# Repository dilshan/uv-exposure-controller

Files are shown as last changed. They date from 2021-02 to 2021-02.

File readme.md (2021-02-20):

## ATTiny2313 base electronic controller for UV exposure units.

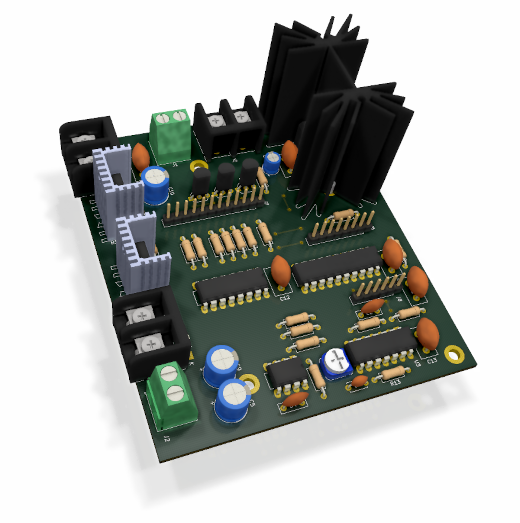
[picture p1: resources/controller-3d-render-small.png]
3D view of the controller PCB


*ATtiny2313A* MCU base exposure controller unit with two high-power relay driver stages, an audible notification unit, a safety lock, and a programmable timer. The programmable timer unit supports up to 999 seconds (approximately 16 minutes) of exposure.

This unit tests with four *NEC* 20W - 60cm (T8) black fluorescent tubes with four separate chokes and starter units.

The unit is specifically designed for developing screens (for screen-printing) and for paint curing.

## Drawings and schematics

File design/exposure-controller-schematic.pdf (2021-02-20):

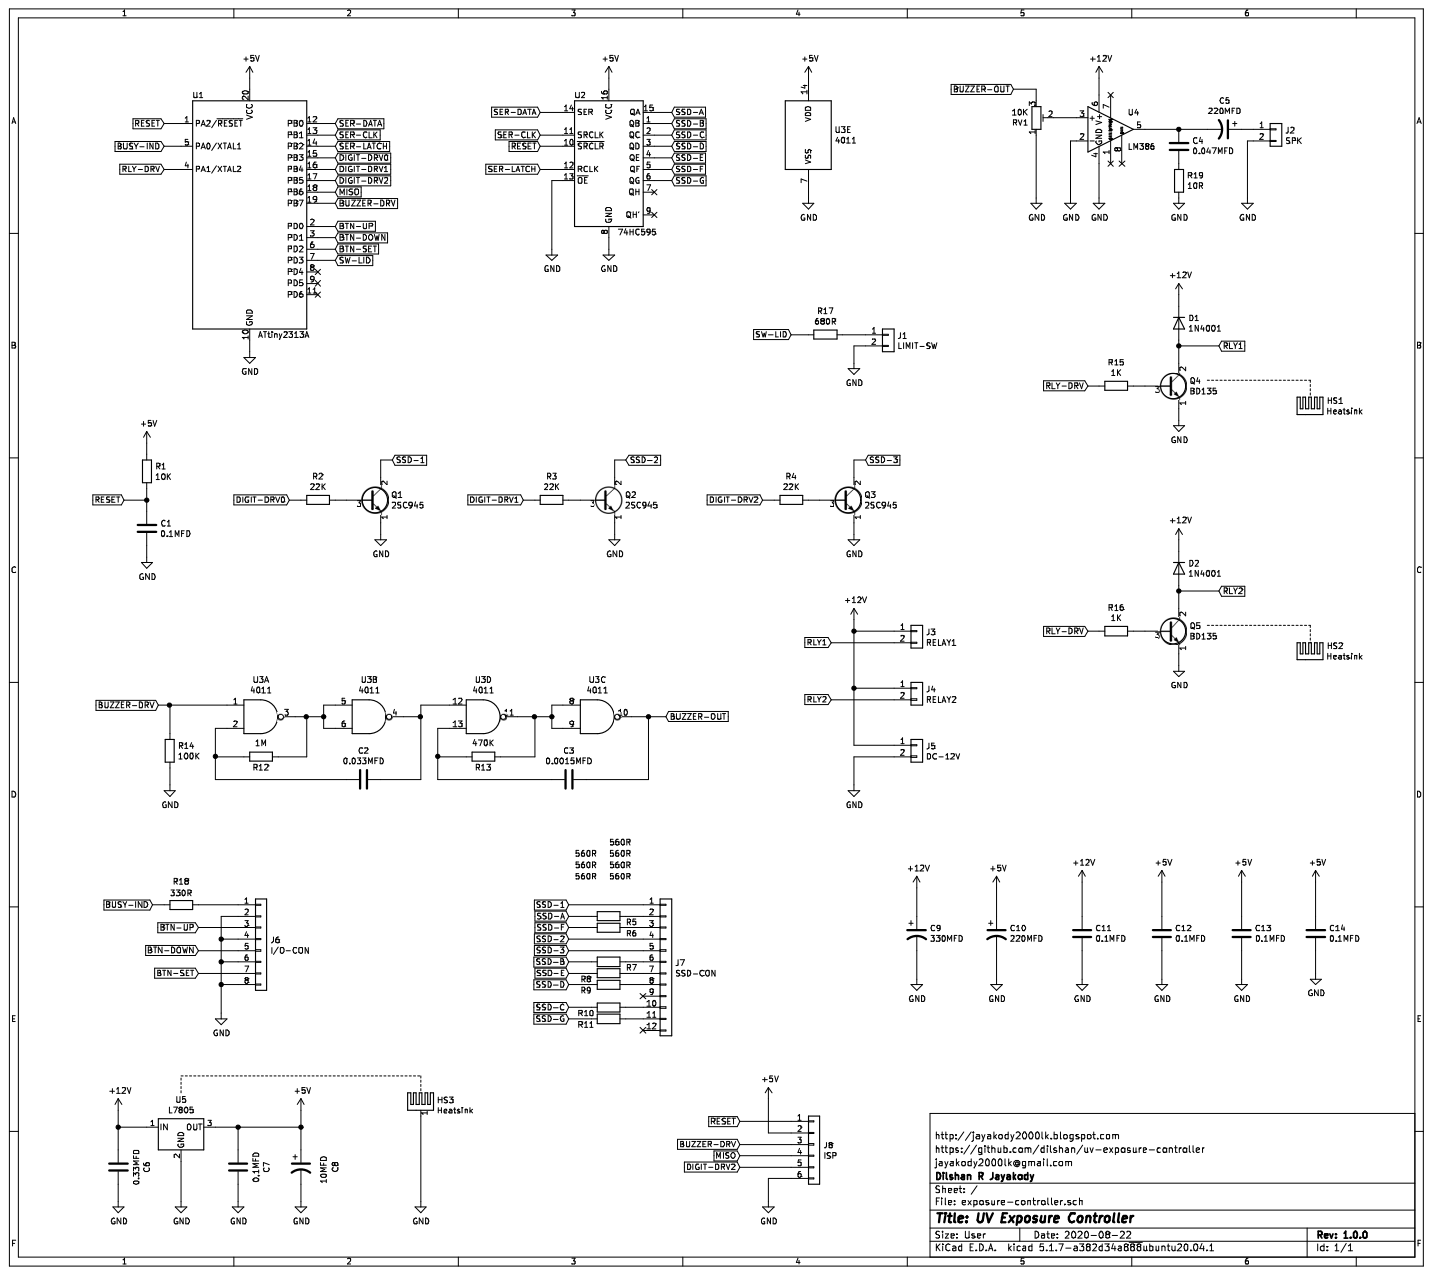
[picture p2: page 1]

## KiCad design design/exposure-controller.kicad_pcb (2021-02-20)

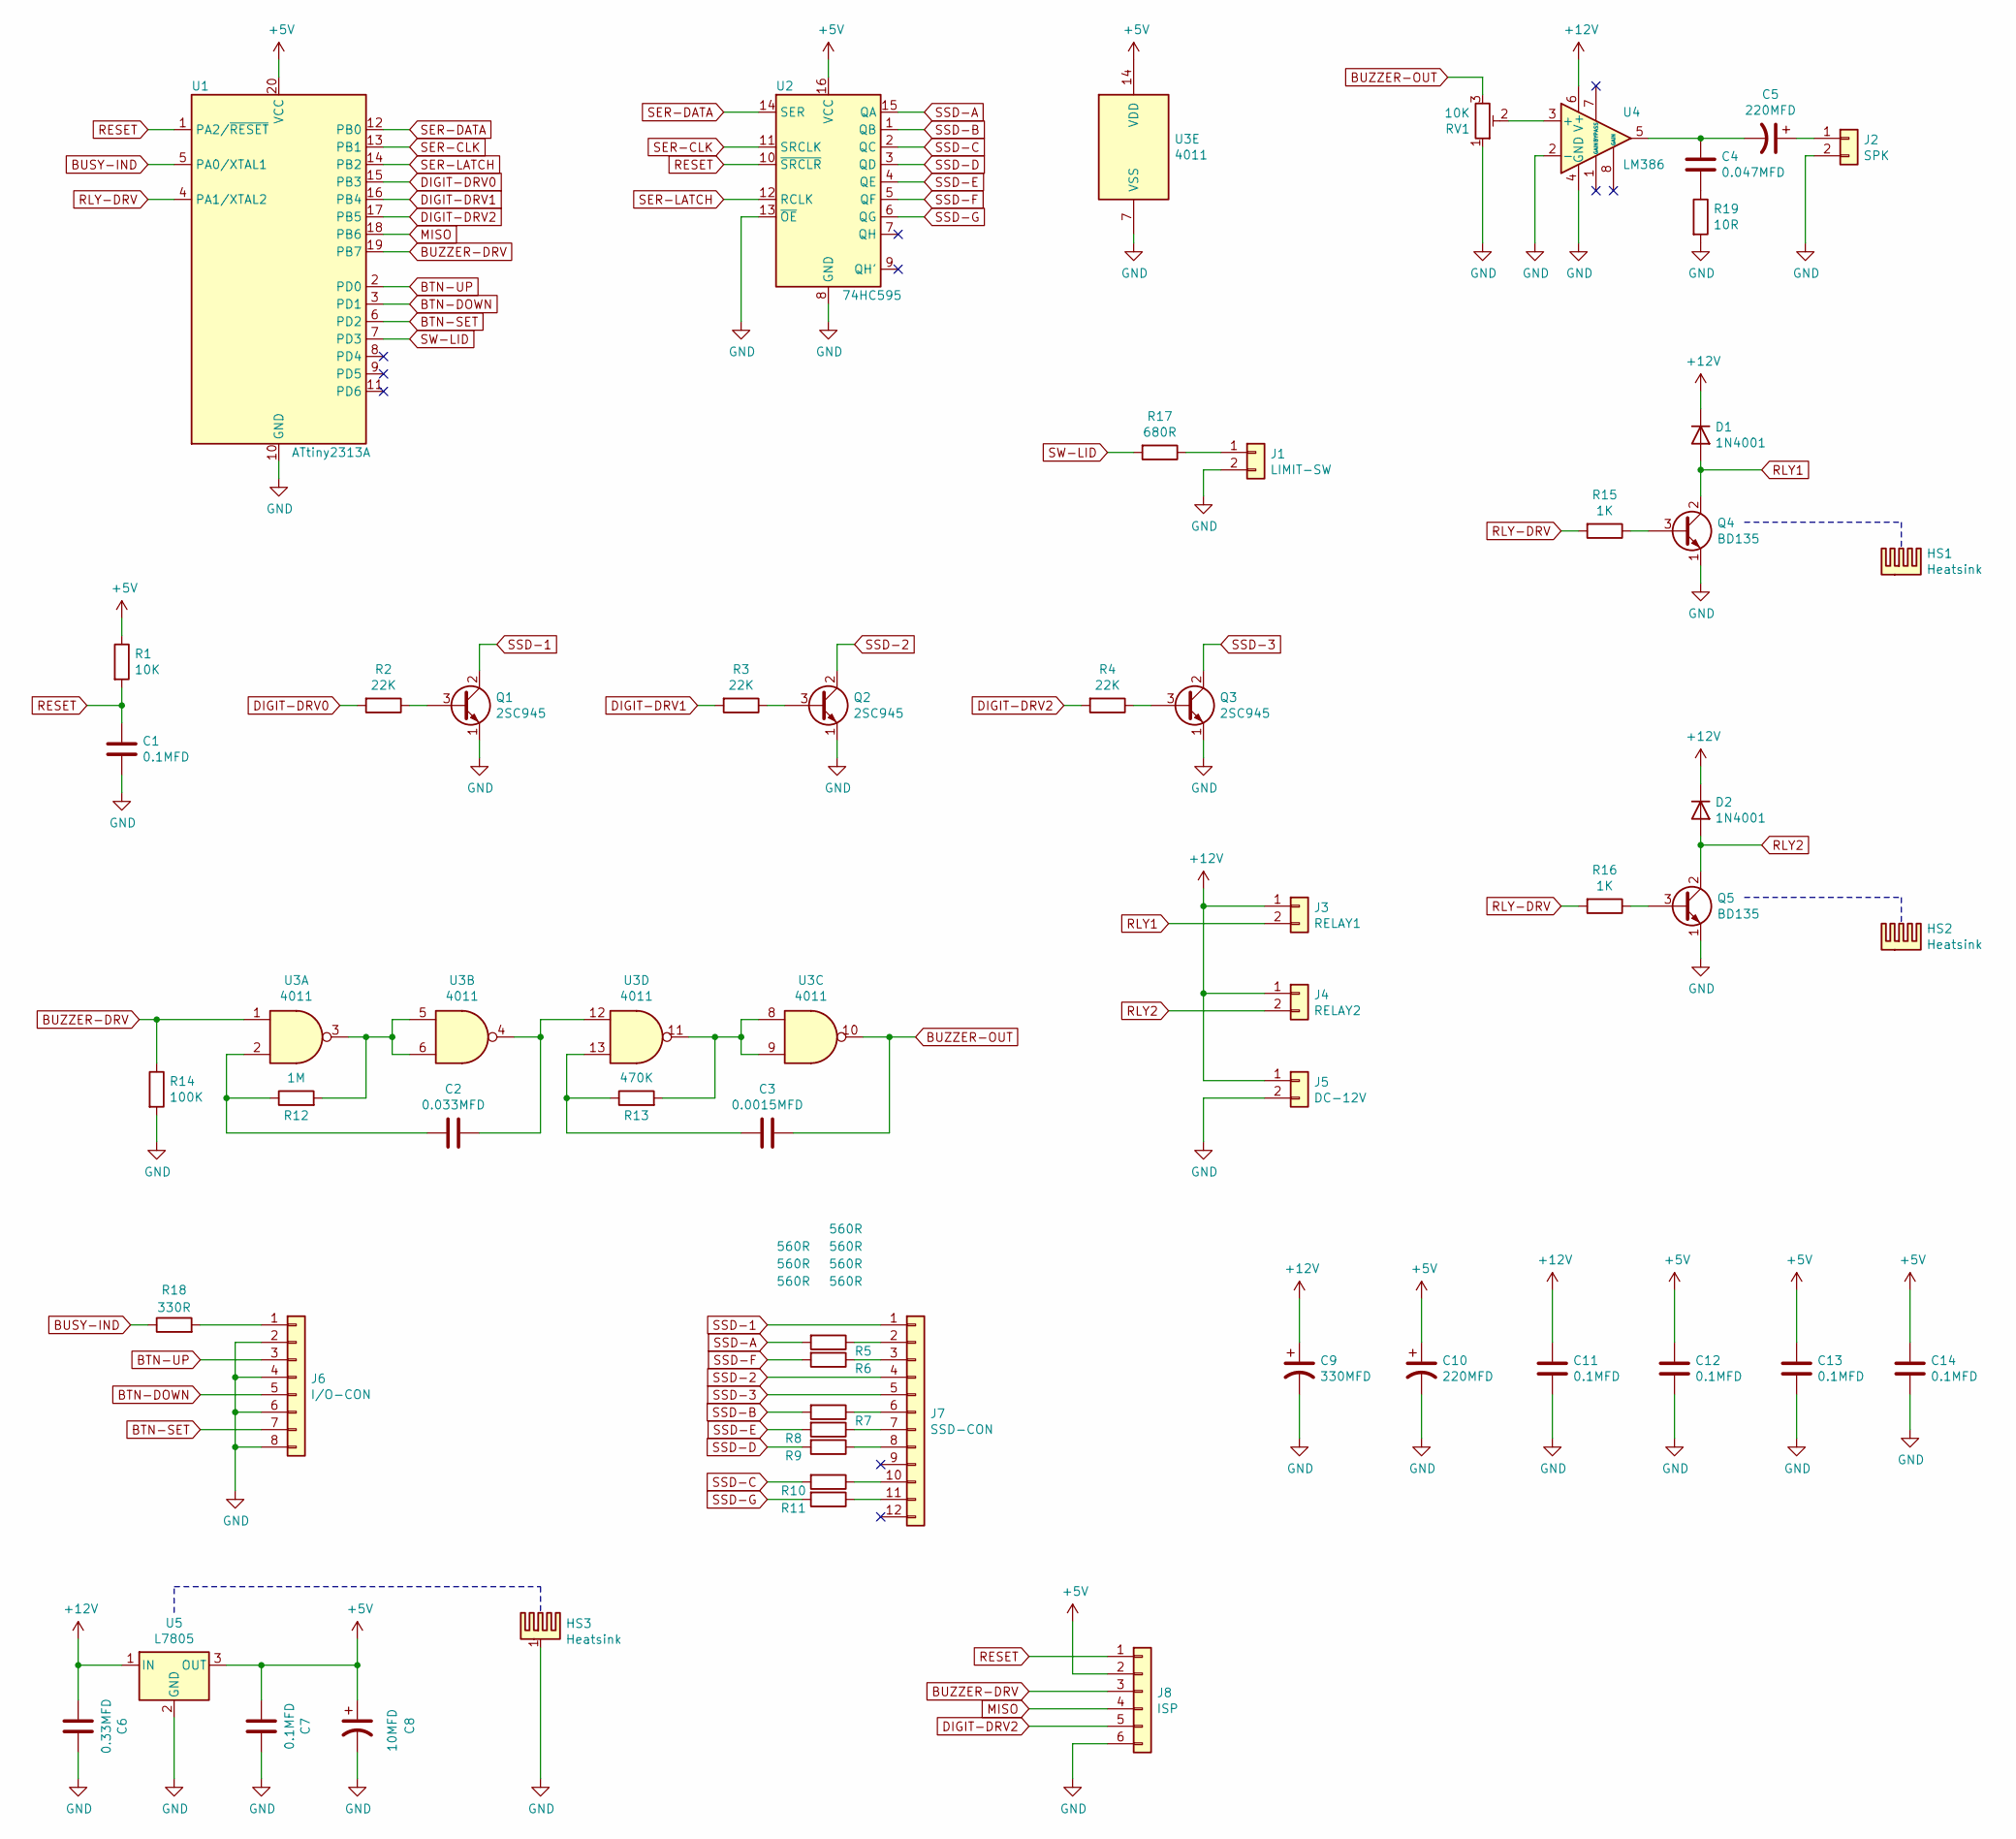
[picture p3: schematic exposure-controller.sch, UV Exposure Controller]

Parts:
C1, C7, C11, C12, C13, C14: 0.1MFD; C_Disc_D9.0mm_W5.0mm_P5.00mm
C2: 0.033MFD; C_Disc_D7.0mm_W2.5mm_P5.00mm
C3: 0.0015MFD; C_Disc_D4.7mm_W2.5mm_P5.00mm
C4: 0.047MFD; C_Disc_D7.0mm_W2.5mm_P5.00mm
C5, C10: 220MFD; CP_Radial_D8.0mm_P3.50mm
C6: 0.33MFD; C_Disc_D11.0mm_W5.0mm_P5.00mm
C8: 10MFD; CP_Radial_D5.0mm_P2.50mm
C9: 330MFD; CP_Radial_D8.0mm_P3.80mm
D1, D2: 1N4001; D_DO-41_SOD81_P10.16mm_Horizontal
HS1, HS2: Heatsink; Hetsink-21mm
HS3: Heatsink; Heatsink_Fischer_SK129-STS_42x25mm_2xDrill2.5mm
J1: LIMIT-SW; TerminalBlock_Phoenix_MKDS-1,5-2-5.08_1x02_P5.08mm_Horizont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
J2: SPK; TerminalBlock_Phoenix_MKDS-1,5-2-5.08_1x02_P5.08mm_Horizont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
J3: RELAY1; MENGFEI 8.5mm screw terminal - 2way
J4: RELAY2; MENGFEI 8.5mm screw terminal - 2way
J5: DC-12V; MENGFEI 8.5mm screw terminal - 2way
J6: I/O-CON; PinHeader_1x08_P2.54mm_Vertical
J7: SSD-CON; PinHeader_1x12_P2.54mm_Vertical
J8: ISP; PinHeader_1x06_P2.54mm_Vertical
Q1, Q2, Q3: 2SC945; TO-92L_Inline_Wide
Q4, Q5: BD135; TO-126-3_Vertical
R1: 10K; R_Axial_DIN0207_L6.3mm_D2.5mm_P10.16mm_Horizontal
R2, R3, R4: 22K; R_Axial_DIN0207_L6.3mm_D2.5mm_P10.16mm_Horizontal
R5, R6, R7, R8, R9, R10, R11: 560R; R_Axial_DIN0207_L6.3mm_D2.5mm_P10.16mm_Horizontal
R12: 1M; R_Axial_DIN0207_L6.3mm_D2.5mm_P10.16mm_Horizontal
R13: 470K; R_Axial_DIN0207_L6.3mm_D2.5mm_P10.16mm_Horizontal
R14: 100K; R_Axial_DIN0207_L6.3mm_D2.5mm_P10.16mm_Horizontal
R15, R16: 1K; R_Axial_DIN0207_L6.3mm_D2.5mm_P10.16mm_Horizontal
R17: 680R; R_Axial_DIN0207_L6.3mm_D2.5mm_P10.16mm_Horizontal
R18: 330R; R_Axial_DIN0207_L6.3mm_D2.5mm_P10.16mm_Horizontal
R19: 10R; R_Axial_DIN0207_L6.3mm_D2.5mm_P10.16mm_Horizontal
RV1: 10K; Potentiometer_Runtron_RM-065_Vertical
U1: ATtiny2313A; DIP-20_W7.62mm_LongPads
U2: 74HC595; DIP-16_W7.62mm_LongPads
U3: 4011; DIP-14_W7.62mm_LongPads
U4: LM386; DIP-8_W7.62mm_LongPads
U5: L7805; TO-220-3_Vertical

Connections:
+5V: C7.2, C8.1, C10.1, C12.1, C13.1, C14.1, J8.2, R1.1, U1.20 (VCC), U2.16 (VCC), U3.14 (VDD), U5.3 (OUT)
+12V: C6.2, C9.1, C11.1, D1.1 (K), D2.1 (K), J3.1, J4.1, J5.1, U4.6 (V+), U5.1 (IN)
BTN-DOWN: J6.5, U1.3 (PD1)
BTN-SET: J6.7, U1.6 (PD2)
BTN-UP: J6.3, U1.2 (PD0)
BUSY-IND: R18.1, U1.5 (PA0/XTAL1)
BUZZER-DRV: J8.3, R14.1, U1.19 (PB7), U3.1
BUZZER-OUT: C3.1, RV1.3, U3.10
DIGIT-DRV0: R2.2, U1.15 (PB3)
DIGIT-DRV1: R3.2, U1.16 (PB4)
DIGIT-DRV2: J8.5, R4.2, U1.17 (PB5)
GND: C1.2, C6.1, C7.1, C8.2, C9.2, C10.2, C11.2, C12.2, C13.2, C14.2, HS3.1, J1.2, J2.2, J5.2, J6.2, J6.4, J6.6, J6.8, J8.6, Q1.1 (E), Q2.1 (E), Q3.1 (E), Q4.1 (E), Q5.1 (E), R14.2, R19.2, RV1.1, U1.10 (GND), U2.8 (GND), U2.13 (~OE), U3.7 (VSS), U4.2 (-), U4.4 (GND), U5.2 (GND)
MISO: J8.4, U1.18 (PB6)
unnamed: C2.1, U3.4, U3.12
unnamed: C2.2, R12.1, U3.2
unnamed: C3.2, R13.1, U3.13
unnamed: C4.1, R19.1
unnamed: C4.2, C5.2, U4.5
unnamed: C5.1, J2.1
unnamed: J1.1, R17.1
unnamed: J6.1, R18.2
unnamed: J7.2, R5.1
unnamed: J7.3, R6.1
unnamed: J7.6, R7.1
unnamed: J7.7, R8.1
unnamed: J7.8, R9.1
unnamed: J7.10, R10.1
unnamed: J7.11, R11.1
unnamed: Q1.3 (B), R2.1
unnamed: Q2.3 (B), R3.1
unnamed: Q3.3 (B), R4.1
unnamed: Q4.3 (B), R15.1
unnamed: Q5.3 (B), R16.1
unnamed: R12.2, U3.3, U3.5, U3.6
unnamed: R13.2, U3.8, U3.9, U3.11
unnamed: RV1.2, U4.3 (+)
RESET: C1.1, J8.1, R1.2, U1.1 (PA2/~RESET), U2.10 (~SRCLR)
RLY1: D1.2 (A), J3.2, Q4.2 (C)
RLY2: D2.2 (A), J4.2, Q5.2 (C)
RLY-DRV: R15.2, R16.2, U1.4 (PA1/XTAL2)
SER-CLK: U1.13 (PB1), U2.11 (SRCLK)
SER-DATA: U1.12 (PB0), U2.14 (SER)
SER-LATCH: U1.14 (PB2), U2.12 (RCLK)
SSD-1: J7.1, Q1.2 (C)
SSD-2: J7.4, Q2.2 (C)
SSD-3: J7.5, Q3.2 (C)
SSD-A: R5.2, U2.15 (QA)
SSD-B: R7.2, U2.1 (QB)
SSD-C: R10.2, U2.2 (QC)
SSD-D: R9.2, U2.3 (QD)
SSD-E: R8.2, U2.4 (QE)
SSD-F: R6.2, U2.5 (QF)
SSD-G: R11.2, U2.6 (QG)
SW-LID: R17.2, U1.7 (PD3)

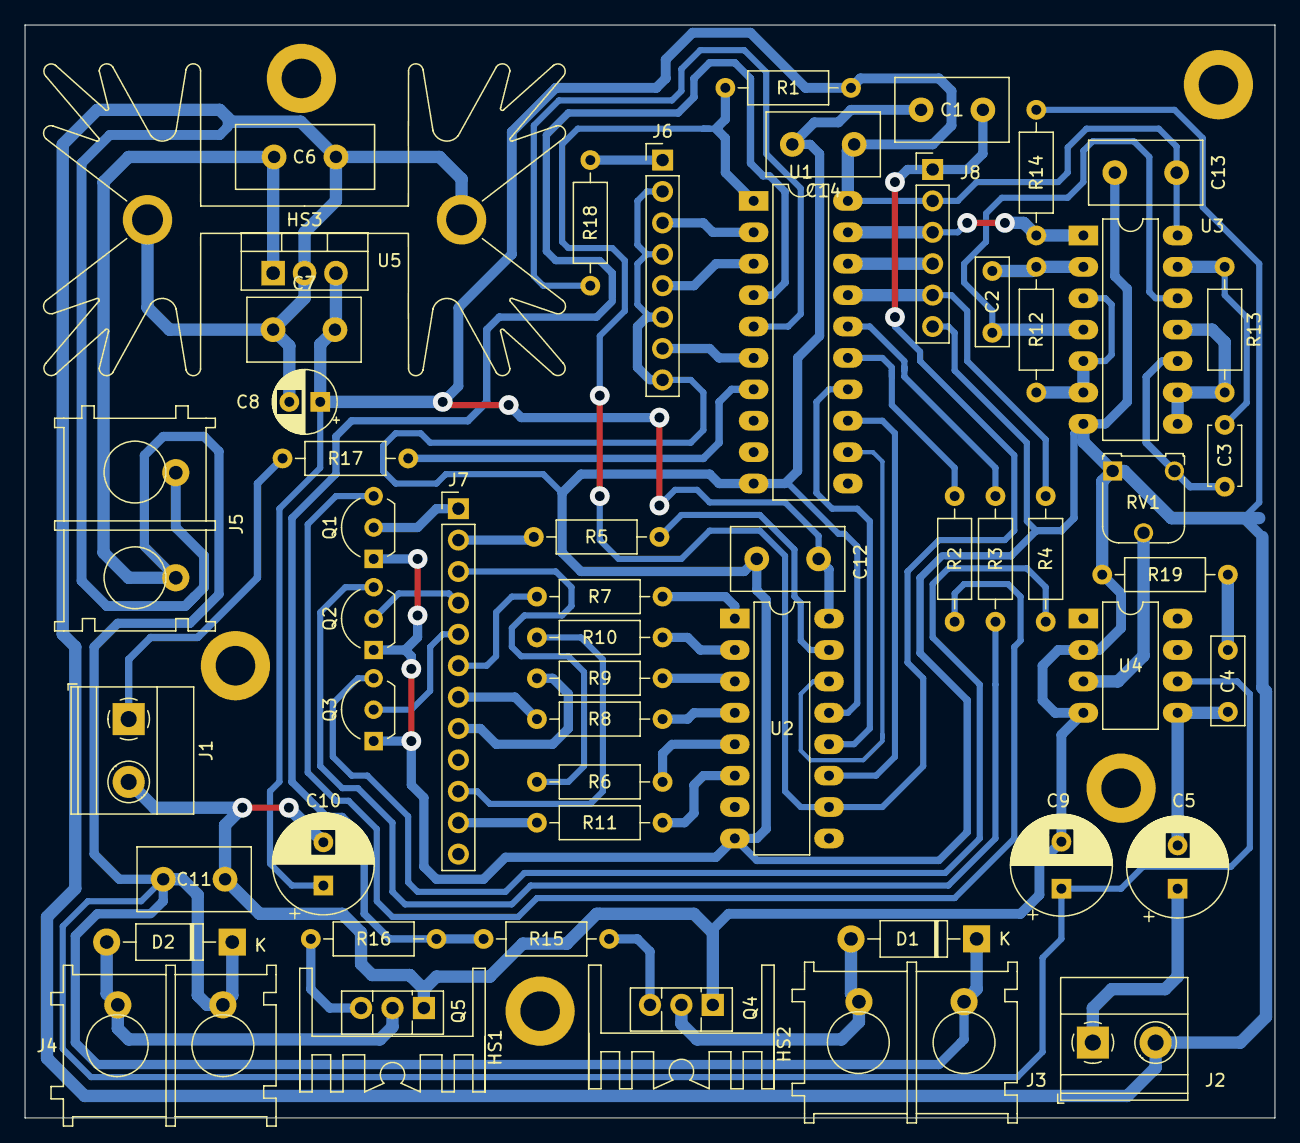
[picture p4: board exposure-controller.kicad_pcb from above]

Board: 2 copper layers, 101.1 x 88.4 mm, 62 parts (0 on the bottom side), 54 nets.

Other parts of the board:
 : MountingHole_3.2mm_M3_DIN965_Pad
 #2,  #3,  #4,  #5: MountingHole_3.2mm_M3_DIN965_Pad

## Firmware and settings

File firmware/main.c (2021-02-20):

//-----------------------------------------------------------------------
// Copyright 2020 Dilshan R Jayakody [jayakody2000lk@gmail.com]
//
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
#include <avr/io.h>

#include "main.h"

#include <util/delay.h>
#include <avr/interrupt.h>
#include <avr/eeprom.h>
#include <avr/wdt.h>

typedef enum SytemState 
{
    IdleState,  // System is in idle state (waiting for action).
    EditState,  // Digit edit state.
    RunState,   // UV timer execute state.
    PauseState  // Timer pause state due to external interrupt.
} SytemState;

SytemState currentState;

uint8_t timerCounter, editDigit;
uint8_t buzzerCounter;
int16_t time, targetTime;

int main()
{
    // Stop Timer 1 and WDT.
    cli();
    wdt_disable();

    TCCR1B = 0x00;
    
    uint8_t lastSwitchState, tempDigit;
    currentState = IdleState;

    // Setup I/O ports.

    // A0 -> Run indicator.
    // A1 -> Relay driver.
    DDRA = 0x03;
    PORTA = 0x00;

    // B0 -> 74HC595 : SER (Serial Input).
    // B1 -> 74HC595 : SRCLK (Shift Register Clock).
    // B2 -> 74HC595 : RCLK (Register Clock).
    // B3 -> Digit 1 driver.
    // B4 -> Digit 2 driver.
    // B5 -> Digit 3 driver.
    // B7 -> 4011 : Buzzer.
    DDRB = 0xFF;
    PORTB = 0x00;

    // D0 -> UP / START button input.
    // D1 -> DOWN / STOP button input.
    // D2 -> SET button input.
    // D3 -> Lid open limit switch.
    DDRD = 0x00;
    PORTD = 0xFF;  

    // Wait to avoid startup spikes.
    _delay_ms(1000);
     
    editDigit = 0;
    timerCounter = 0;
    targetTime = time = MINIMUM_TIME;
    buzzerCounter = 0;

    // Start Timer 1 with 2Hz output.
    TCNT1 = 0;
    OCR1A = 15624;
    
    TCCR1A = 0x00;
    TCCR1B = 0x0C;
    TIMSK = TIMSK | 0x40;

    sei();

    lastSwitchState = PIND; 
    wdt_enable(WDTO_4S);

    // Read time setting from EEPROM and validate the limits.
    time = eeprom_read_word((uint16_t * )0);
    if((time < MINIMUM_TIME) || (time > MAXIMUM_TIME))
    {
        // Current time is out of bounds.
        time = MINIMUM_TIME;
    }

    wdt_reset();
    targetTime = time;

    // Main service loop.
    while (1)
    {
        if(((PIND & 0x01) == 0x01) && ((lastSwitchState & 0x01) == 0x00))
        {
            // Start / Increment button pressed.
            if(currentState == EditState)
            {
                // Increase the value of the current digit.
                tempDigit = extractDigit();
                tempDigit = ((tempDigit == 9) ? 0 : (tempDigit + 1));
                updateDigit(tempDigit);

                timerCounter = 0;                
            }
            else if(currentState == IdleState)
            {                
                // Start UV timer.
                time = targetTime;
                timerCounter = 0;
                PORTA = 0x03;
                currentState = RunState;
            }
        }

        if(((PIND & 0x02) == 0x02) && ((lastSwitchState & 0x02) == 0x00))
        {
            // Stop / Decrement button pressed.
            if(currentState == EditState)
            {
                // Decrease the value of the current digit.
                tempDigit = extractDigit();
                tempDigit = ((tempDigit == 0) ? 9 : (tempDigit - 1));
                updateDigit(tempDigit);

                timerCounter = 0;
            }
            else if(currentState == RunState)
            {
                // Stop UV timer.
                currentState = IdleState;
                time = targetTime;                
                PORTA = 0x00;

                // Trigger buzzer with short beep.
                timerCounter = 1;
                buzzerCounter = 2;
                PORTB = PORTB | 0x80;
            }
        }

        if(((PIND & 0x04) == 0x04) && ((lastSwitchState & 0x04) == 0x00))
        {
            // Set button pressed.
            if(currentState == IdleState)
            {
                // Enter into time edit mode.
                currentState = EditState;
                editDigit = 0;
            }
            else if(currentState == EditState)
            {
                // Move editor into next digit.
                editDigit++;

                if(editDigit > 2)
                {
                    // All digits are updated and leave the edit mode.
                    if(time < MINIMUM_TIME)
                    {
                        // Specified time is less than minimum time interval. Reset time to minimum.
                        time = MINIMUM_TIME;
                    }

                    editDigit = 0;
                    targetTime = time;

                    // Load new time value into EEPROM.
                    wdt_reset();
                    if(targetTime != eeprom_read_word((uint16_t * )0))
                    {
                        eeprom_write_word((uint16_t*)0, targetTime);
                    }

                    wdt_reset();
                    currentState = IdleState;
                }
            }
        }

        if(currentState == RunState)
        {            
            if(time <= 0)
            {            
                // UV exposure countdown completed.
                currentState = IdleState;
                time = targetTime;
                PORTA = 0x00;

                // Trigger buzzer with long beeps.
                timerCounter = 1;
                buzzerCounter = 6;
                PORTB = PORTB | 0x80;
            }

            if((PIND & 0x08) == 0x08)
            {
                // Lid has been open.
                PORTA = 0x00;
                currentState = PauseState;                
            }
        }

        if((currentState == PauseState) && ((PIND & 0x08) == 0x00))
        {
            // Lid has been closed.            
            currentState = RunState;
            PORTA = 0x03;
        }

        lastSwitchState = PIND; 
        wdt_reset();
        setNumber();        
    }
        
    return 0;
}

uint8_t extractDigit()
{    
    uint8_t digit1, digit2, digit3;

    // Extract digit values.
    digit1 = time / 100;
    digit2 = (time - (digit1 * 100)) / 10;
    digit3 = time - (int16_t)((digit1 * 100) + (digit2 * 10));

    switch (editDigit)
    {
    case 0:
        return digit1;
    case 1:
        return digit2;
    case 2:
        return digit3;
    }

    return 0;
}

void updateDigit(uint8_t newValue)
{
    uint8_t digit1, digit2, digit3;
    digit1 = time / 100;
    digit2 = (time - (digit1 * 100)) / 10;
    digit3 = time - (int16_t)((digit1 * 100) + (digit2 * 10));

    switch (editDigit)
    {
    case 0:
        digit1 = newValue;
        break;
    case 1:
        digit2 = newValue;
        break;
    case 2:
        digit3 = newValue;
        break;
    }

    // Create new time value with specified digit data and extracted data.
    time = digit3 + (digit2 * 10) + ((int16_t)(digit1 * 100));
}

uint8_t getDigit(uint8_t value, uint8_t showZero)
{
    switch (value)
    {
    case 0:  
        if(currentState == EditState)  
        {
            // In edit mode show all zero digits.
            return 0x3F;
        }
        else
        {
            // Flag to shutdown leading zeros.
            return showZero ? 0x3F : 0x00;
        }                
    case 1:
        return 0x30;
    case 2:
        return 0x5B;
    case 3:
        return 0x4F;
    case 4:
        return 0x66;
    case 5:
        return 0x6D;
    case 6:
        return 0x7D;
    case 7:
        return 0x07;
    case 8:
        return 0x7F;
    case 9:
        return 0x6F;  
    default:
        return 0;
    }
}

uint8_t getDigitMode(uint8_t pos)
{
    if(currentState == EditState)
    {
        if((timerCounter == 1) && (pos == editDigit))
        {
            // Enter into single digit blink mode.
            return 0;
        }
    }
    else if(currentState == PauseState)
    {
        if(timerCounter == 1)
        {
            // Enter into full (3-digit) blink mode.
            return 0;
        }
    }
    
    return (1 << (pos + 3));   
}

void setNumber()
{
    uint8_t digit1, digit2, digit3;
    digit1 = time / 100;
    digit2 = (time - (digit1 * 100)) / 10;
    digit3 = time - (int16_t)((digit1 * 100) + (digit2 * 10));

    // Update 1st digit of the seven segment display.
    PORTB = PORTB & 0xC7;
    setDigitValue(getDigit(digit1, (time > 99)));
    PORTB = PORTB | getDigitMode(0);
    _delay_ms(2);

    // Update 2nd digit of the seven segment display.
    PORTB = PORTB & 0xC7;
    setDigitValue(getDigit(digit2, (time > 9)));
    PORTB = PORTB | getDigitMode(1);
    _delay_ms(2);

    // Update 3rd digit of the seven segment display.
    PORTB = PORTB & 0xC7;
    setDigitValue(getDigit(digit3, 1));
    PORTB = PORTB | getDigitMode(2);
    _delay_ms(2);

    PORTB = PORTB & 0xC7;
}

void setDigitValue(uint8_t value)
{
    // Initialize shift register input terminals to known state.
    int8_t dataPos;
    PORTB = PORTB & 0xF8;

    for(dataPos = 7; dataPos >= 0; dataPos--)
    {
        // Set data value.
        PORTB = PORTB | ((value & (1 << dataPos)) ? 0x01 : 0x00);
        _delay_us(2);

        // Load data into register.
        PORTB = PORTB | 0x02;
        _delay_us(5);
        PORTB = PORTB & 0xF8;
        _delay_us(2);
    }

    // Latch data into output.
    PORTB = PORTB | 0x04;
    _delay_us(5);
    PORTB = PORTB & 0xF8;
}

ISR(TIMER1_COMPA_vect) 
{
    timerCounter++;

    if(timerCounter == 2)
    {
        // 1 second time trigger.
        timerCounter = 0;

        if((currentState == RunState) && (time > 0))
        {
            // Update UV light timer.
            time--;
        }
    }

    // Check status of the buzzer flag.
    if(buzzerCounter > 0)
    {
        buzzerCounter--;

        if(buzzerCounter == 0)
        {
            // Mute buzzer.
            PORTB = PORTB & 0x7F;
        }
        else
        {
            // Activate and mute buzzer terminal based on timer counter value.
            PORTB = (timerCounter % 2) ? (PORTB | 0x80) : (PORTB & 0x7F);
        }                
    }
}

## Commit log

2021-02-20 Initial version of controller board design & ATtiny2313 firmware.
    [exposure-controller.kicad_pcb, exposure-controller.sch]
2021-02-20 Add 3D view of the controller PCB. :framed_picture:
2021-02-20 Add PDF version of the schematic.
